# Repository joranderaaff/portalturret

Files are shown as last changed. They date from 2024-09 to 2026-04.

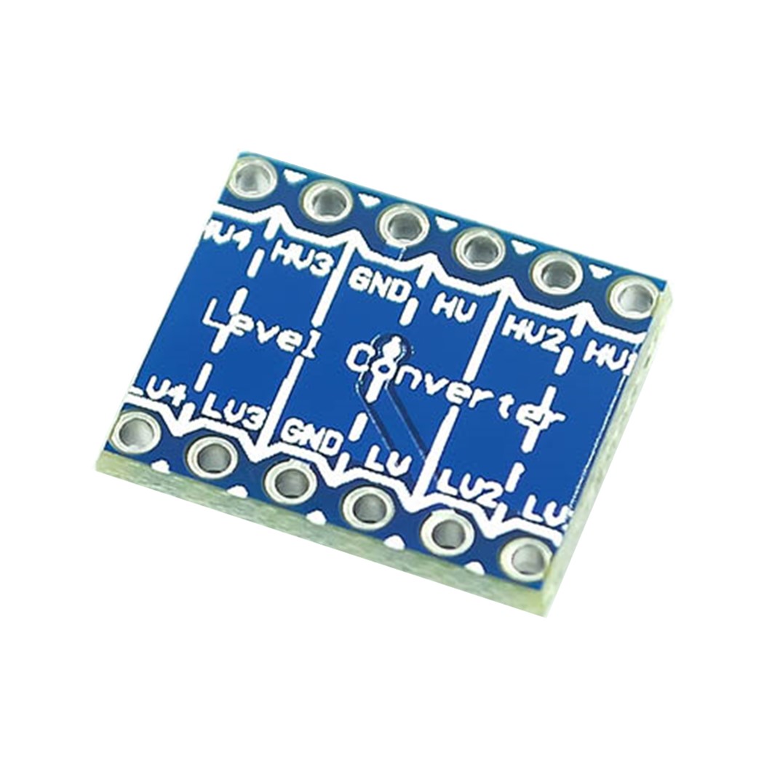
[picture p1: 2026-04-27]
electronics/v3/docs/i2c-voltage-level-converter.jpg

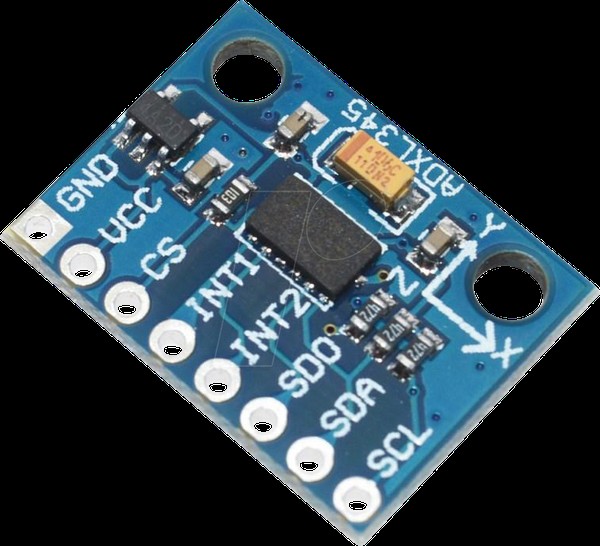
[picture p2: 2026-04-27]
electronics/v3/docs/ADXL345.jpg

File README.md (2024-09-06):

# DIY Portal Sentry - firmware sourcecode

Homepage: https://joranderaaff.nl/portal-sentry/

# Build

- Install [VSCode](https://code.visualstudio.com/download)
- Install [PlatformIO](https://marketplace.visualstudio.com/items?itemName=platformio.platformio-ide)
- Install [nodejs](https://nodejs.org/en/download)
- In VSCode -> Open bash shell (or git bash) and type `./make.sh` to build webpage
- In VSCode -> At the bottom, choose your env -> PlatformIO -> Upload

# Environments

- `esp8266_d1_mini` for v2 (custom PCB)
- `esp8266_d1_mini_legacy` for v1 (PCA Board)

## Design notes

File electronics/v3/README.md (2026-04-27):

# Portal Electronics v3

## Bill of Materials

| Qty | Part | Function | Image |
| --- | --- | --- | --- |
| 1 | ADXL345 accelerometer | Motion/orientation sensing | [ADXL345.jpg](docs/ADXL345.jpg) |
| 1 | MAX98357 amplifier | I2S audio amplifier | [max98357.jpg](docs/max98357.jpg) |
| 1 | AMS1117_3V3 power supply | 3.3 V voltage regulation | - |
| 1 | Wemos S2 Mini CPU | Main controller board | [Wemos-S2-Mini.jpg](docs/Wemos-S2-Mini.jpg) |
| 1 | 4 Way IIC I2C Level Conversion Module | I2C voltage level conversion | [i2c-voltage-level-converter.jpg](docs/i2c-voltage-level-converter.jpg) |
| 1 per LED | 20 ohm SMD resistor | LED current limiting | - |
| 2 | 4.7 uF SMD capacitor | Power supply decoupling | - |

## Assembly Notes

- Bridge the `RG` pads and use one `20 ohm` resistor per gun LED
- Use one `20 ohm` SMD resistor for RC
- Fit two `4.7 uF` SMD capacitors for C33_1 C33_2

## Reference

- [PCB preview](docs/pcb.jpg)
- [Final build PCB 1](docs/pcb_1.jpg)
- [Final build PCB 2](docs/pcb_2.jpg)

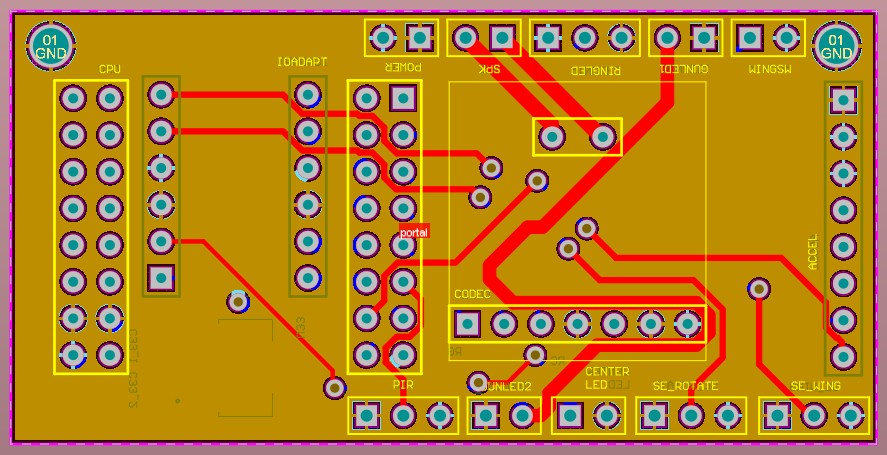
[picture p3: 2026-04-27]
electronics/v3/docs/pcb.jpg

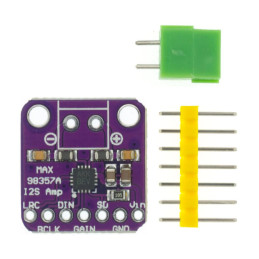
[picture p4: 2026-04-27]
electronics/v3/docs/max98357.jpg

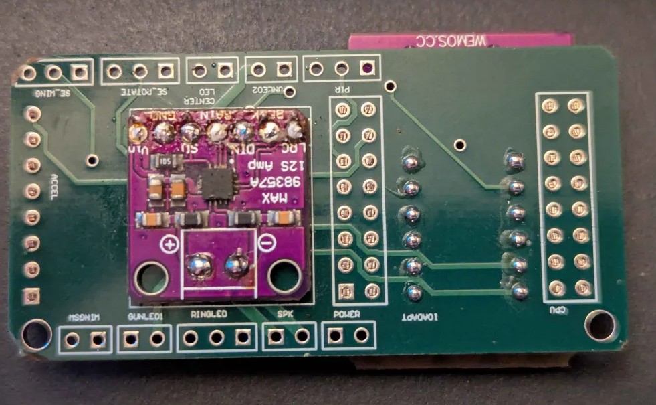
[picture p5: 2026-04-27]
electronics/v3/docs/pcb_2.jpg

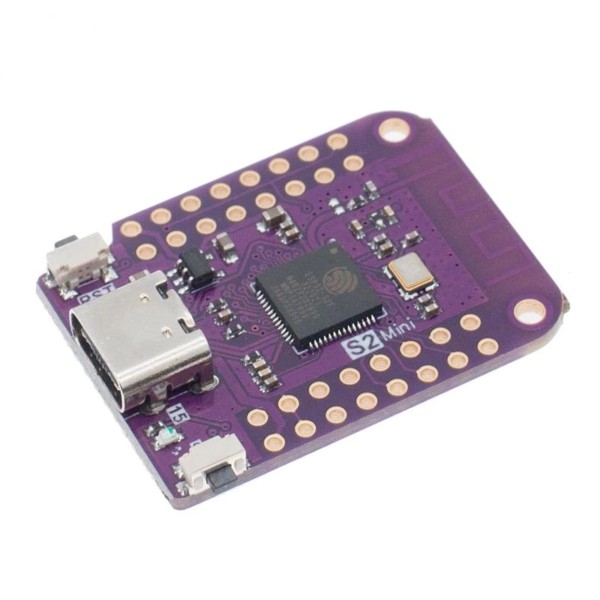
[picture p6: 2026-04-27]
electronics/v3/docs/Wemos-S2-Mini.jpg

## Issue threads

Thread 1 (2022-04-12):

wemos mount step/f360 file

abrugsch, 2022-04-12:
Thanks for the great project!
Can you provide the step or F360 file for the wemos mount? I have an older D1 mini and I'd like to modify the bracket for the difference in the module that I have (has a discrete 8266 module on the carrier board)

joranderaaff, 2022-04-18:
Hi! I'll get back to you soon. Was a bit busy. I'll see if I can upload the
files for the WeMos for you.

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

abrugsch, 2022-04-21:
Thanks! I have quite a bit of printing still to do so it's not urgent. I will of course contribute the modified version back to the project :)

joranderaaff, 2022-04-28:
Hi Alistair!

I think I got a STEP file for you of the Wemos mount.. Where do you want me
to send it?
Maybe send your actual email address so I can send it to you?

All the best,

Joran

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

abrugsch, 2022-05-02:
You could just add it to the github repo, or in the same place as the rest of the 3D files.

Otherwise my email is the name on my github account, firstname.lastname@gmail

AeroX2, 2023-03-07:
Hey I'm also really interested in getting access to the CAD files,
I'm looking to make some small modifications and I would really appreciate it!

My email is `james @ snoopyaustralia.com`

Thanks

joranderaaff, 2023-03-07:
I've added the STEP file to the repo for version 2.0 of the turret.

abrugsch, 2023-03-08:
Is there much change in V2? I had to re-start my build after most of my printed parts warped in a hot car. I've already picked up the redone wings with added support, has much else changed or just code?

Ev0lve712, 2024-03-04:
Good afternoon, I’m currently assembling a turret, when will I have a chance to take a look at v2?

joranderaaff, 2024-03-04:
The STEP file should be V2. Are there issues with this file for you?

joranderaaff, 2024-03-04:
Please refer to this page to check pin numbering: https://www.wemos.cc/en/latest/d1/d1_mini_3.1.0.html

There's two kinds: **Pin** and **GPIO Pin**. So D8 is the same as GPIO15.

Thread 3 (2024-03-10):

Servo WINGS

Ev0lve712, 2024-03-10:
Good afternoon, I have a problem with servos. The drive responsible for the wings turns only 5-10 degrees. One way and the other.
What could be the problem?

In the video I used a sketch of an example of "ServoPWM".
https://github.com/joranderaaff/portalturret/assets/62849202/2445906e-4ed4-423f-b45a-8d70ccbdb51a

joranderaaff, 2024-03-11:
Hi there. I can think of a few things:

- Some servos have slightly different timing when it comes to the PWM signal. These are parameters you can set when initializing the servos. See this page for information on how to tweak: https://www.arduino.cc/reference/en/libraries/servo/attach/
- Is this a regular servo, or did you use a 360 servo by accident? Those two have different characteristics, where "normal" servos are meant to move to a specific angle, and 360 servos move (counter) clockwise depending on the signal you send.

Ev0lve712, 2024-03-18:
Good day, thank you for the information provided. Indeed, I had both servos with limited angles, I ordered a new one, connected it, it began to rotate endlessly, changed the frequency to “53”, it stopped, according to tests it works well. I'm slowly starting to assemble the turret.

Closed 2024-09-06.

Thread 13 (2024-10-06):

missing config file ?

pepouille, 2024-10-06:
Hi,

I've printed and mostly finished build the 3D object; also ordered some PCB and assembled it. (still missing the accelerometer board, but it is on its way...)

Anyway, I wanted to try the software already, just to hear if some sound for example could be produced.
I'm using a wemos D1 mini clone; I first flashed it with the firmware.bin image you provided.
I couldn't get anything from the speaker, but I could connect to the device's wifi using my phone, and gets redirected to the captive portal, interface was working, but as I didn't have all the servo and so on ready, I couldn't fully test it yet.

I've installed all the building chain and was, after some trick, being able to compile and upload the compiled firmware.
(I'm under linux, not windows; in some of your file, you are including a file with name pins.h, in other it is Pins.h, which is, I suppose, the same file; if under dos/windows, upper/lower-case name doesn't matters apparently, it is not the same under a linux fs. Anyway, I didn't touch the sources files and rather created a symbolic name of Pins.h -> pins.h which did the trick)

I saw the ssid "Portal turret" on my phone, but couldn't connect to it properly this time.

I then open Arduino IDE to have a look at the messages on the serial line; I saw a problem :
"Failed to open settings for reading..."

I've then tried to get the spiffs partition from the device using the "make.sh fs_get"; I modified the script somewhat to avoid it to delete the downloaded fs.bin file; I then extract it in a directory using :

littlefs-python extract fs.bin fs --block-size=4096

and indeed there were no file in fs.

I've then looked for the same kind of information using your firmware.bin, and with it, I couldn't mount the filesystem (it report a corrupted FS)

Is it normal ?

joranderaaff, 2024-10-07:
Ah, yes Windows doesn't allow me to change caps, as it will think it's the same file. Rather annoying.

That message about settings is expected. As long as you don't log in to your network OR change something in the settings page, no saving is triggered and it will not create such a settings file. The message is a bit misleading, as the turret should function just fine without that file being there.

If you want to test separate functions, there is a diagnose page that allows you to try hardware, but if you run into issues I strongly advice to create separate small sketches to make sure things work like you would expect.

Not being able to connect the second time is strange though.

Closed 2024-11-10.

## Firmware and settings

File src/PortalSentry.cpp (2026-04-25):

// General
#include <Arduino.h>
#include "Pins.h"

#ifdef LEGACY
#include <Adafruit_PWMServoDriver.h>
#define FREQ 50 // one clock is 20 ms
#define FREQ_MINIMUM 205  // 1ms is 1/20, of 4096
#define FREQ_MAXIMUM 410  // 2ms is 2/20, of 4096
Adafruit_PWMServoDriver pwm = Adafruit_PWMServoDriver();
#endif

#ifndef HARDWARE_V3
#include <SoftwareSerial.h>
SoftwareSerial softwareSerial(AUDIO_RX, AUDIO_TX);
#endif

// Why do I have to include this here? Servo.h otherwise found twice?
#include <ESPAsyncWebServer.h>

#include "LEDs.h"
#include "Sensors.h"
#include "Servos.h"
#include "Settings.h"



Settings settings;

#ifdef USE_AUDIO_CARL
#include "Audio_carl.h"
Audio audio(settings, softwareSerial);

#elif HARDWARE_V3
#include "ESP32Audio.h"
Audio audio(settings);

#elif USE_SERIAL_MP3
#include "Audio_TD5580A.h"
Audio audio(settings, AUDIO_RX, AUDIO_TX);

#elif USE_AUDIO
#include "Audio.h"
Audio audio(settings, softwareSerial);

#else
#include "Audio_dummy.h"
Audio audio(settings);
#endif

Sensors sensors(settings);
Servos servos(settings, sensors);
LEDs leds;

#include "Routines.h"
#include "StateBehaviour.h"
#include "PortalServer.h"

void setup() {

#ifdef LEGACY
  pwm.begin();
  pwm.setPWMFreq(FREQ);
#endif

#if defined(ESP32)
  Serial.begin(115200);
#ifdef WAIT_FOR_SERIAL
  pinMode(LED_BUILTIN, OUTPUT);
  digitalWrite(LED_BUILTIN, HIGH);
  while (!Serial) {
    digitalWrite(LED_BUILTIN, !digitalRead(LED_BUILTIN));
    delay(100);
  }
#endif
#else
  Serial.begin(74880);
#endif
  settings.Begin();
  sensors.Begin();
  leds.Begin();
  servos.Begin();
  servos.CloseWings();
#if defined(USE_AUDIO) && not defined(LEGACY) && not defined(HARDWARE_V3)
  Serial.println("Ending serial communications, enabling audio");
  delay(300);
  Serial.end();
#endif
  audio.Begin();

  StartServer();

  currentTurretMode = settings.startInManualMode == 1 ? TurretMode::Manual
                                                      : TurretMode::Automatic;

  leds.SetCenterLEDBrightness(255);
  leds.FillLEDRing();
}

void loop() {
  sensors.UpdateSensors();
  leds.UpdateLEDs();
  UpdateStateBehaviour();
  UpdateServer();
#ifdef HARDWARE_V3
  audio.Loop();
#endif
}

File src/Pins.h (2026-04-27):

#pragma once

#ifdef ESP32
    #ifdef HARDWARE_V3
        #define SDA 14
        #define SCL 13
        #define SERVO_WING 6
        #define SERVO_ROTATE 4
        #define WING_SWITCH 3
        #define PIR 11
        #define CENTER_LED 8
        #define GUN_LEDS 10
        #define RING_LEDS 12
        #define BCK 7
        #define WS 9
        #define DOUT 5
    #else
        #define AUDIO_BUSY 5
        #define SERVO_WING 11
        #define SERVO_ROTATE 9
        #define WING_SWITCH 7
        #define PIR 2
        #define CENTER_LED 18
        #define GUN_LEDS 16
        #define RING_LEDS 12
        #define AUDIO_RX 37
        #define AUDIO_TX 39
    #endif
#else
    #define RING_LEDS D8
    #ifdef LEGACY
        #define AUDIO_BUSY A0
        #define WING_SWITCH D0
        #define PIR D7
        #define CENTER_LED 0
        #define GUN_RIGHT 14
        #define GUN_LEFT 15
        #define SERVO_WING 7
        #define SERVO_ROTATE 8
        #define AUDIO_RX D5
        #define AUDIO_TX D6
    #else
        #define AUDIO_BUSY D0
        #define WING_SWITCH D5
        #define PIR A0
        #define GUN_RIGHT 13
        #define GUN_LEFT 12
        #define SERVO_ROTATE 12        
        #define SERVO_WING 13
        #define CENTER_LED D3
        #define GUN_LEDS D4
        #define AUDIO_RX RX
        #define AUDIO_TX TX
    #endif
#endif

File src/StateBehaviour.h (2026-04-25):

#ifndef PT_STATE_BEHAVIOUR
#define PT_STATE_BEHAVIOUR

#include "Servos.h"
#include "Settings.h"
#include <Arduino.h>

enum class TurretMode { Automatic = 0, Manual = 1, Idle = 2 };

enum class TurretState {
  Idle = 0,
  Activated = 1,
  Searching = 2,
  Engaging = 3,
  TargetLost = 4,
  PickedUp = 5,
  Shutdown = 6,
  ManualEngaging = 7,
  Rebooting = 8,
};

enum class ManualState {
  Idle,
  Opening,
  Closing,
  Firing,
};

TurretMode currentTurretMode = TurretMode::Automatic;
TurretState currentState = TurretState::Idle;
ManualState currentManualState = ManualState::Idle;

unsigned long detectTime = 0;
unsigned long undetectTime = 0;
unsigned long previousTime = 0;
unsigned long stateStartTime = 0;
unsigned long lastMovementTime = 0;

long panicBuffer = 0;

bool diagnoseMode;
int diagnoseAction;

void setState(TurretState nextState) {
  // Stop the Wing Servos just in case;
  servos.SetWingAngle(settings.idleAngle);

  if (currentTurretMode == TurretMode::Automatic) {
    switch (nextState) {
    case TurretState::Idle:
      // Handle Idle state if necessary
      break;
    case TurretState::Activated:
      activatedRoutine.reset();
      break;
    case TurretState::Engaging:
      engagingRoutine.reset();
      break;
    case TurretState::Searching:
      searchingRoutine.reset();
      break;
    case TurretState::TargetLost:
      targetLostRoutine.reset();
      break;
    case TurretState::PickedUp:
      pickedUpRoutine.reset();
      break;
    case TurretState::Shutdown:
      shutdownRoutine.reset();
      break;
    case TurretState::ManualEngaging:
      manualEngagingRoutine.reset();
      break;
    case TurretState::Rebooting:
      rebootRoutine.reset();
      break;
    }
    stateStartTime = millis();
    currentState = nextState;
  }
}

void setManualState(ManualState nextState) {
  // Stop the Wing Servos just in case;
  servos.SetWingAngle(settings.idleAngle);

  if (currentTurretMode == TurretMode::Manual) {
    switch (nextState) {
    case ManualState::Idle:
      // Handle Idle state if necessary
      break;
    case ManualState::Opening:
      openWingsRoutine.reset();
      break;
    case ManualState::Closing:
      closeWingsRoutine.reset();
      break;
    case ManualState::Firing:
      manualEngagingRoutine.reset();
      break;
    }
    currentManualState = nextState;
  }
}

void manualRotation(unsigned long deltaTime) {
  manualMovementRoutine.runCoroutine();
}

void UpdateStateBehaviour() {
  if (!diagnoseMode) {
    unsigned long deltaTime = millis() - previousTime;
    previousTime = millis();

    if (currentTurretMode == TurretMode::Manual) {
      switch (currentManualState) {
      case ManualState::Idle:
        manualRotation(deltaTime);
        break;
      case ManualState::Opening:
        openWingsRoutine.runCoroutine();
        if (openWingsRoutine.isDone()) {
          setManualState(ManualState::Idle);
        }
        break;
      case ManualState::Closing:
        closeWingsRoutine.runCoroutine();
        if (closeWingsRoutine.isDone()) {
          setManualState(ManualState::Idle);
        }
        break;
      case ManualState::Firing:
        manualRotation(deltaTime);
        manualEngagingRoutine.runCoroutine();
        if (manualEngagingRoutine.isDone()) {
          setManualState(ManualState::Idle);
        }
        break;
      }
    }
    if (currentTurretMode == TurretMode::Automatic) {

      bool motionDetected = sensors.IsDetectingMotion();

      float zMovement = (sensors.smoothZ / MEASUREMENTS *
                         SENSORS_GRAVITY_STANDARD * ADXL345_MG2G_MULTIPLIER);
      float xMovement = (sensors.smoothX / MEASUREMENTS *
                         SENSORS_GRAVITY_STANDARD * ADXL345_MG2G_MULTIPLIER);
      float yMovement = (sensors.smoothY / MEASUREMENTS *
                         SENSORS_GRAVITY_STANDARD * ADXL345_MG2G_MULTIPLIER);

      bool pickedUp = sensors.accelerometerBuffered &&
                      (xMovement < -settings.panicTreshold ||
                       xMovement > settings.panicTreshold ||
                       yMovement < -settings.panicTreshold ||
                       yMovement > settings.panicTreshold);
      bool movedAround = sensors.accelerometerBuffered &&
                         (xMovement < -settings.restTreshold ||
                          xMovement > settings.restTreshold ||
                          yMovement < -settings.restTreshold ||
                          yMovement > settings.restTreshold);
      bool onItsSide = sensors.accelerometerBuffered &&
                       (zMovement < settings.tippedOverTreshold);

      if (movedAround) {
        lastMovementTime = millis();
      }

      if (pickedUp) {
        panicBuffer += deltaTime;
      } else {
        panicBuffer -= deltaTime;
        if (panicBuffer < 0) {
          panicBuffer = 0;
        }
      }

      if (panicBuffer > 250 && currentState != TurretState::PickedUp &&
          currentState != TurretState::Shutdown &&
          currentState != TurretState::Rebooting) {
        setState(TurretState::PickedUp);
      }
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

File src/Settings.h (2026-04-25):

#ifndef PT_SETTINGS
#define PT_SETTINGS

#include <Arduino.h>
#include <ArduinoJson.h>
#include <LittleFS.h>
#include "Pins.h"

class Settings {
public:
  String wifiSSID;
  String wifiPassword;
  String language = "english";
  String audioUrl = "https://joranderaaff.nl/portal-sentry/audio/";
  uint8_t audioVolume = 10;
  int startInManualMode = 0;
  int openDuration = 1000;
  int maxRotation = 50;
  int centerAngle = 90;
  int idleAngle = 90;
  int wingRotateDirection = 1;
  int wingPin = SERVO_WING;
  int rotatePin = SERVO_ROTATE;
  float panicTreshold = 3;
  float restTreshold = 1;
  float tippedOverTreshold = 5;

  Settings() {}
  void Begin() {
    if (!LittleFS.begin()) {
      Serial.println("Littlefs error. Formatting...");
      LittleFS.format();
      LittleFS.begin();
    }

    // static Settings settings;
    Serial.println("Loading settings...");

    File file = LittleFS.open(settingsFilePath, "r");
    if (!file) {
      Serial.println("Failed to open settings file for reading");
      return;  // Return default settings
    }

    // Create a JSON document to read the settings
    JsonDocument doc;
    DeserializationError error = deserializeJson(doc, file);
    if (error) {
      Serial.println("Failed to parse settings file");
      return;  // Return default settings
    }

    // Assign values from JSON to settings structure
    if (doc.containsKey("wifiSSID"))
      wifiSSID = doc["wifiSSID"].as<String>();
    if (doc.containsKey("wifiPassword"))
      wifiPassword = doc["wifiPassword"].as<String>();
    if (doc.containsKey("language"))
      language = doc["language"].as<String>();
    if (doc.containsKey("audioUrl"))
      audioUrl = doc["audioUrl"].as<String>();
    if (doc.containsKey("audioVolume"))
      audioVolume = doc["audioVolume"].as<int>();
    if (doc.containsKey("centerAngle"))
      centerAngle = doc["centerAngle"].as<int>();
    if (doc.containsKey("idleAngle"))
      idleAngle = doc["idleAngle"].as<int>();
    if (doc.containsKey("wingRotateDirection"))
      wingRotateDirection = doc["wingRotateDirection"].as<int>();
    if (doc.containsKey("wingPin"))
      wingPin = doc["wingPin"].as<int>();
    if (doc.containsKey("rotatePin"))
      rotatePin = doc["rotatePin"].as<int>();
    if (doc.containsKey("openDuration"))
      openDuration = doc["openDuration"].as<int>();
    if (doc.containsKey("maxRotation"))
      maxRotation = doc["maxRotation"].as<int>();
    if (doc.containsKey("panicTreshold"))
      panicTreshold = doc["panicTreshold"].as<float>();
    if (doc.containsKey("restTreshold"))
      restTreshold = doc["restTreshold"].as<float>();
    if (doc.containsKey("tippedOverTreshold"))
      tippedOverTreshold = doc["tippedOverTreshold"].as<float>();
    if (doc.containsKey("startInManualMode"))
      startInManualMode = doc["startInManualMode"].as<int>();

    file.close();
    Serial.println(SettingsToJSON());
  }

  // Function to save settings to the filesystem
  void SaveSettings() {
    Serial.println("Saving settings");
    File file = LittleFS.open(settingsFilePath, "w");
    if (!file) {
      Serial.println("Failed to open settings file for writing");
      return;
    }

    // Create a JSON document to store the settings
    JsonDocument doc;
    
    doc["wifiSSID"] = wifiSSID;
    doc["wifiPassword"] = wifiPassword;
    doc["language"] = language;
    doc["audioUrl"] = audioUrl;
    doc["audioVolume"] = audioVolume;
    doc["centerAngle"] = centerAngle;
    doc["idleAngle"] = idleAngle;
    doc["wingRotateDirection"] = wingRotateDirection;
    doc["wingPin"] = wingPin;
    doc["rotatePin"] = rotatePin;
    doc["openDuration"] = openDuration;
    doc["maxRotation"] = maxRotation;
    doc["panicTreshold"] = panicTreshold;
    doc["restTreshold"] = restTreshold;
    doc["tippedOverTreshold"] = tippedOverTreshold;
    doc["startInManualMode"] = startInManualMode;

    Serial.println("Updated JSON");

    // Serialize JSON to file
    if (serializeJson(doc, file) == 0) {
      Serial.println("Failed to write to settings file");
    }

    Serial.println("Saved settings to file");

    file.close();
  }
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

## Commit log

2022-03-20 Full first commit of the Arduino project for the Portal Turret
2022-08-24 Working on V2 of the portal turret with the custom PCB.
2024-08-02 Added rotate direction for some 360 servos
2024-08-05 Reverted states, needs more thorough look
    [LEDs.h, PortalSentry.ino, StateBehaviour.h]
2024-08-12 Fixed almost all issues with the legacy turret
    [LEDs.h, PortalSentry.ino, Sensors.h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]
2024-08-12 Fixed brightness for center LED
    [LEDs.h]
2024-08-26 minor fix for port
    [Sensors.h]
2024-09-01 switch to script shell make (for windows without make)
2024-09-02 port for esp32
2024-09-04 add audio for esp32, fix test leds, fix littlefs config path
    [partitions.csv]
2024-09-06 Renamed Pins file to use capital. ESP32 now stil uses settings to define pins for servos.
2024-09-07 Fixed manual moving of turret
    [PortalServer.h]
2024-09-09 get sounds from portal2 vpk, autodownload sounds if needed, add hardware v3 (different pin mapping + i2s codec), add factory reset (keep GPIO0 pushed AFTER boot)
    [partitions.csv]
2024-09-09 Added missing diagnose options
    [StateBehaviour.h]
2024-10-07 Print out information about ending "normal" serial communication and switch to audio
2024-10-07 Print an error if ADXL345 is not starting properly
    [Sensors.h]
2024-10-07 Add monitor_filters to allow nicer stack trace formatting
2024-11-03 fixed legacy version, updated deprecated functions
    [ESP32Downloader.cpp, LEDs.h, Pins.h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]
2024-11-10 Pin dependency
2026-04-20 Fix reboot, add delay to flush wifi response
    [PortalServer.h]
2026-04-20 remove serial.println that was never reached
2026-04-20 Initialize all Sensors member variables to prevent undefined behavior on startup
    [Sensors.h]
2026-04-25 Fixed error in JSON Serialization
    [Settings.h]
2026-04-25 Fixed limiting the polling of the analog pin
    [Sensors.h]
2026-04-25 Finally fixed the pins for Wing and Rotate servos
2026-04-27 add esp32 pcb for electronics v3
    [Portal.PrjPcb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]
2026-04-27 add final hardware v3 + rename PID to PIR
